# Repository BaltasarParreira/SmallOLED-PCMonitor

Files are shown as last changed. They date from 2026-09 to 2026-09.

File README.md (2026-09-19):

# PC Stats Monitor - ESP32 OLED Display

Youtube Video (https://www.youtube.com/watch?v=D6zZIyOvWjY)

3D Printable case:
0.96": https://makerworld.com/en/models/2051935

1.3": https://makerworld.com/en/models/2185211

2.42" https://makerworld.com/en/models/2341351

Be aware that there are different sizes of the same SSD1306 (0.96") OLED screen on aliexpress.
Im using this one "Original" version (do not purchase dual color, it won't work):
It seems that there is also "New" screen version which comes in another 2 sizes. So be sure to pick correct 3D printable case from link above.
https://aliexpress.com/item/1005006262908701.html

For 1.3" OLED (SH1106) I have used this version:
https://aliexpress.com/item/1005009757205826.html

For 2.42" OLED (SSD1309) I have used this version:
https://aliexpress.com/item/4000002579405.html

For 1.54" OLED (CH1116) I have used this version:
https://aliexpress.com/item/1005006579037427.html

ESP32-C3 SuperMini:
https://aliexpress.com/item/1005008988143743.html

HOW TO Video assembly (you can ignore LED if you are not going to use it):

Version with LED based on 2n2222: https://www.youtube.com/watch?v=umV7xA0mp5I

Version with LED based on LDO6AJSA https://www.youtube.com/watch?v=M2Oa4PDUUgE

I have noticed that some of the cheap ESP32-C3 boards have WiFi related issues on hardware level. After some additional implementations to the code in attempt to fix issues (v1.2.1), some of those issues cannot be fixed as they are on hardware level.
What has helped a bit: Soldering 2 pins to the side of antenna. Check video assembly where I'm sixing that issue.
Some of those faulty boards have antenna too close to other components. Like in this example (left side with 3.5mm gap is better)



> **Note:** Some ESP32-C3 SuperMini boards (especially the external antenna variant) have a very bright built-in RGB LED (WS2812) on GPIO 8. Since GPIO 8 is used for I2C SDA, this LED cannot be turned off via software. If it bothers you, desolder the LED or cut its data trace on the PCB.

A real-time PC monitoring system that displays CPU, RAM, GPU, and disk stats on a small OLED screen using ESP32 and a companion Python script.

## Custom PCB, sponsored by PCBWay

There is now a 27 x 27 mm carrier PCB that holds the ESP32-C3 SuperMini, the OLED header and the optional filament LED driver on one board, instead of wiring it by hand. **[PCBWay](https://www.pcbway.com/) sponsored this project and manufactured the boards**, SMT assembly included, shown below and in the assembly video.

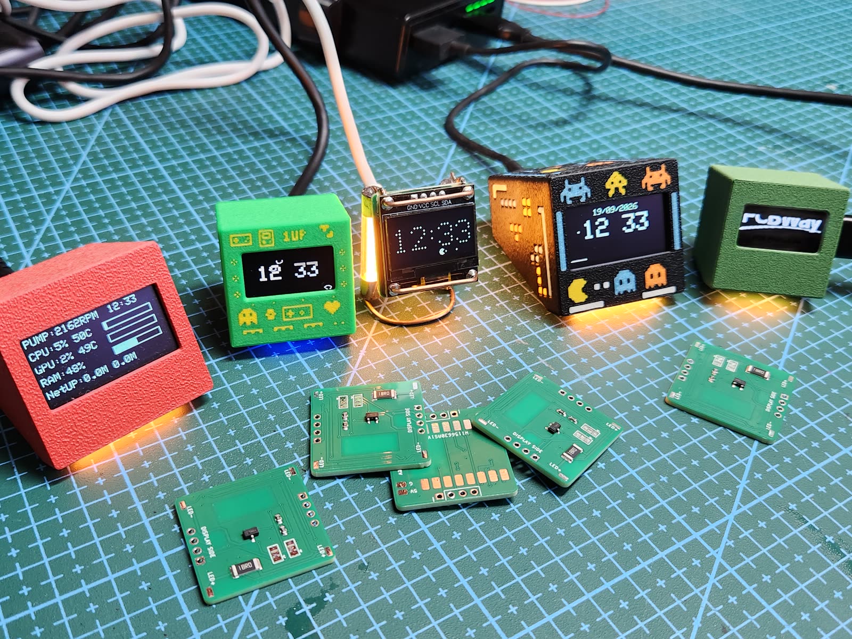
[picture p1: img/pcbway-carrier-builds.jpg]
Finished SmallOLED builds next to unpopulated carrier PCBs


- **[Board details and build notes](CARRIER-PCB.md)**
- **[Order the board from PCBWay](https://www.pcbway.com/project/shareproject/SmallOLED_Carrier_27x27_mm_ESP32_C3_SuperMini_board_for_an_I2C_OLED_PC_stats_m_c42149ed.html)** (gerbers, BOM and pick and place files are attached to the shared project)
- **[Full assembly video](https://youtu.be/5O7uISlaXd4)**: flashing from the browser, soldering, antenna mod and enclosure
- **Cases for this board**: [0.96" (3MF)](case/SmallOLED-Case-0.96-PCB.3mf) and [1.3" retro (3MF)](case/SmallOLED-Case-1.3-Retro-PCB.3mf), two plates each. See [CARRIER-PCB.md](CARRIER-PCB.md#3d-printed-cases) before printing the 1.3" one, it needs a panel-mount USB-C on a lead

## Features

- **Dual Display Modes:**
  - **PC Online**: Real-time stats with customizable metrics and positions
  - **PC Offline**: Animated clock (Mario, Space Invaders, Arkanoid, Pac-Man, Snake, Tetris, Asteroids, Dino Runner, TRON, Standard, or Large styles, plus a Cycle All mode)
- **Audio Visualizer**: Live spectrum bars or an oscilloscope driven by whatever your PC is playing, streamed by the companion app
- **PC Companion App (v4, Windows + Linux)**:
  - Web-style config window that mirrors the device portal 1:1
  - Live 1:1 OLED preview with drag-and-drop layout
  - Sensor picker with live values, up to 20 metrics
  - Custom labels (max 10 characters), number formats, quick templates
  - Optional audio visualizer stream, with auto-switch when music starts
  - Runs in a native window + system tray; **Start with Windows** autostart
  - Windows prebuilt exe (no Python) or Linux from source
- **Web Configuration Portal**: Customize all settings via browser
  - 5-row (spacious) or 6-row (compact) display modes
  - Large 2-row and 3-row modes for readability at a distance
  - Progress bars for visual representation
  - Clock styles and animation settings
  - Automatic timezone with DST support (56 regions)
  - Display brightness control and scheduled night dimming
  - Export/Import configuration
  - OTA firmware updates
- **Browser Web Flasher (Preferred)**: Install firmware and push WiFi credentials entirely from the browser over USB - no tools to install
- **WiFi Portal**: Easy first-time setup without code changes (fallback / build-from-source path)
- **mDNS Discovery**: Access your device via `http://smalloled.local` (configurable name)
- **Optimized Performance**: Minimal CPU usage on PC (<1%)
- **Persistent Settings**: All preferences saved to ESP32 flash memory

## Quick Start for Beginners

**Never done this before? Here's the simple version:**

1. **Flash ESP32** - Open the [SmallOLED Web Flasher](https://smalloled.stolaris.dev/) in desktop Chrome or Edge, pick your OLED, and click Install (no installation needed!)
2. **Connect ESP32 to WiFi** - Right after flashing, use the flasher's **Configure WiFi** step to send your network to the device over USB. (No web flasher? Join the "PCMonitor-Setup" network and open 192.168.4.1.)
3. **Install LibreHardwareMonitor** (Windows only) - Download from [GitHub](https://github.com/LibreHardwareMonitor/LibreHardwareMonitor/releases), run as Admin (needed for temps/fans/GPU/power)
4. **Get the companion app (v4 - recommended on both Windows and Linux):**
   - **Windows (easiest):** download `pc_stats_monitor_v4.exe` from the [latest release](https://github.com/Keralots/SmallOLED-PCMonitor/releases/latest) and double-click it - no Python needed. v4 gives a polished **web-style config window** (1:1 device preview, drag-and-drop layout, sensor picker, number formats, quick templates) that lives in the system tray. On the first run Windows SmartScreen may say *"Windows protected your PC"* - the exe is unsigned, so click **More info -> Run anyway**. This is normal for small unsigned tools.
   - **Linux:** `cd PC-Companion-App-v4/linux-companion`, then `python3 -m pip install -r requirements.txt` and `python3 pc_stats_monitor_v4_linux.py` (no build step). Same UI; opens a native window or your browser.
5. **Configure in GUI** - Enter ESP32 IP address, select the sensors you want, click "Save & Start"
6. **Position metrics** - use the app's **Layout & preview** page, or open the ESP32 IP in a browser and drag metrics on the device's own preview

Done! Your PC stats will now appear on the OLED display.

For detailed instructions, keep reading below.

## Hardware Requirements

### ESP32 Setup
- **ESP32-C3 Super Mini** (or compatible ESP32 board)
- **OLED Display** (128x64, I2C):
  - SSD1306 0.96" (most common)
  - SH1106 1.3" (larger, recommended)
  - CH1116 1.54" (SH1106-compatible, own firmware)
  - SSD1309 2.42" (largest, uses same firmware as 0.96")
- **TTP223 Touch Sensor** (optional - for physical button control)
- **Wiring (I2C):**
  - SDA → GPIO 8
  - SCL → GPIO 9
  - VCC → 3.3V
  - GND → GND
  - TTP223 Signal → GPIO 7 (optional)
  - LED Transistor Base or LDO6AJSA PWM → GPIO 1 (optional)

Wiring



### Touch Button (Optional)
##### Wiring for optional filament led and TTP223 sensor

This wiring is for 2.42" OLED. Use the same firmware as for 0.96" OLED for flashing.
No need to change firmware, TTP223 and LED will work.

If you are using 2N2222 and resistors for led here is the wiring:


If you are using LDO6AJSA here is the wiring:


The firmware supports an optional **TTP223 capacitive touch sensor** for physical control of the display and LED night light:

**Button Gestures:**

| Gesture | Duration | Action |
|---|---|---|
| Quick tap | < 500ms | **PC online:** Toggle metrics/clock. **PC offline:** Cycle clock styles |
| Medium press | 500ms-1s, release | Toggle LED night light on/off |
| Long hold | > 1s, keep holding | Ramp LED brightness up (if off) or down (if on). Release to keep. |

**Hardware Setup:**
- Connect TTP223 signal pin to GPIO 7
- Power the TTP223 with 3.3V and GND

**Configuration** (in `src/config/user_config.h`):
```cpp
#define TOUCH_BUTTON_ENABLED 1      // 1 = enabled, 0 = disabled
#define TOUCH_BUTTON_PIN 7          // GPIO pin (default: 7)
#define TOUCH_DEBOUNCE_MS 50       // Debounce delay (default: 100ms)
#define TOUCH_ACTIVE_LEVEL HIGH     // HIGH for TTP223 (active HIGH)
```

## Software Setup

### 1. ESP32 Firmware

#### Option A: SmallOLED Web Flasher (Preferred - No Installation Needed)

A dedicated browser flasher that picks the right firmware for your OLED, installs it over USB, and then hands your WiFi to the device in the same tab. No separate flashing tool and no captive portal needed.

1. Open the **[SmallOLED Web Flasher](https://smalloled.stolaris.dev/)** in desktop **Chrome or Edge** (Web Serial is required, so Firefox, Safari and mobile won't work).
2. Connect your ESP32-C3 via USB. If it constantly connects/disconnects, hold the **BOOT** button, connect to USB while still holding it, then release after connecting. Alternatively, hold **BOOT**, press **RESET** while holding **BOOT**, then release both buttons.
3. Pick your OLED (0.96" SSD1306, 1.3" SH1106, 1.54" CH1116, or 2.42" SSD1309) and click **Install**. It erases and writes the full image at `0x0` in ~30 seconds.
4. When the install finishes, use the **Configure WiFi** step to send your home network to the device over USB. If you miss it, join the **PCMonitor-Setup** hotspot and open `192.168.4.1` instead.
5. The device reboots, joins your WiFi, and shows its IP address on the OLED.

> The same page has a built-in serial monitor (section 04) for grabbing boot logs if you ever need them for a bug report.

#### Option B: Manual Pre-built Binary (Optional)

Prefer to flash the raw binary with your own tool? Download it from the latest release and flash the full image at `0x0`.

**Download the latest release**: grab the full image for your OLED size from the [Releases tab](https://github.com/Keralots/SmallOLED-PCMonitor/releases/latest).

**Generic web flasher (esptool-js):**
1. Visit [ESP Web Flasher](https://espressif.github.io/esptool-js/)
2. Connect your ESP32-C3 via USB (use the BOOT/RESET trick above if it won't stay connected).
3. Click **"Connect"** and select your port
4. Click **"Choose File"** and select the full image for your display, e.g. `firmware-<version>-OLED_0.96inch.bin`
5. Make sure you pick firmware for correct OLED size version! It may initially work but you will get black screen after you reconnect device.
6. Set **Flash Address** to `0x0`
7. Click **"Program"** and wait ~30 seconds
8. Done! Then set up WiFi via the **PCMonitor-Setup** hotspot (see below).

**Other methods:**
- **Windows**: Run `flash.bat` and follow prompts
- **Linux/Mac**: Run `./flash.sh` and follow prompts
- **Manual**: `esptool.py --chip esp32c3 --port COM3 --baud 460800 write_flash 0x0 firmware-<version>-OLED_0.96inch.bin`

#### Option C: Build from Source

**Prerequisites:**
- [PlatformIO](https://platformio.org/) (or Arduino IDE)

**Installation:**
1. Clone this repository
2. Open the project in PlatformIO
3. Connect your ESP32 via USB
4. Build and upload:
   ```bash
   pio run --target upload
   ```

#### First-Time WiFi Setup

> Flashed with the SmallOLED Web Flasher (Option A)? You can skip this - set WiFi from the browser's **Configure WiFi** step right after flashing. The access-point method below is the fallback, and the path when you build from source.

1. After uploading, the ESP32 will create a WiFi access point
2. Connect to the network: **PCMonitor-Setup**
3. Open your browser to `192.168.4.1`
4. Configure your WiFi credentials
5. The ESP32 will connect and display its IP address on the OLED

#### Web Configuration Portal
Once connected to WiFi, access the full configuration page:
1. Open a browser and navigate to the ESP32's IP address (shown on OLED) or `http://smalloled.local`

ESP32 Web Portal - Clock Settings

2. **Clock Settings:**
   - Idle clock style (Mario, Space Invaders, Arkanoid, Pac-Man, Snake, Tetris, Asteroids, Dino Runner, TRON, Standard, or Large, plus a Cycle All mode)
   - Time format (12/24 hour)
   - Date format (DD/MM/YYYY, MM/DD/YYYY, or YYYY-MM-DD)

3. **Display Layout:**
   - Choose between 5-row (spacious, 13px) or 6-row (compact, 10px) modes
   - Large 2-row and 3-row modes for double-size text
   - Enable progress bars for visual representation
   - Row 6 positions automatically hidden in 5-row mode
4. **Timezone:**
   - Select your region from 56 timezone presets
   - Automatic DST transitions (no manual toggle needed)
5. **Visible metrics (custom labels & placement):**
   - Give each metric a custom label (max 10 chars) shown on the OLED - e.g. relabel a pump RPM sensor as "PUMP", "FAN" or "COOLER"
   - Drag a metric chip onto the live OLED preview (or tap a chip then a slot) to place it
   - Pair two metrics on one row and add progress bars
   - Labels can also be set from the companion app
6. **Configuration:**
   - Export configuration to JSON file (backup)
   - Import configuration from JSON file (restore)
   - Reset to factory defaults

### 2. PC Stats Sender

> **Recommended (v4, Windows + Linux):** the v4 companion gives a web-style
> config window that mirrors the device portal 1:1 - live OLED preview, drag-and-drop
> layout, sensor picker, number formats, quick templates, pull/push and backup -
> all from the desktop, hosted in a native window + system tray.
> - **Windows:** prebuilt **`pc_stats_monitor_v4.exe`** on the [latest release page](https://github.com/Keralots/SmallOLED-PCMonitor/releases/latest) - no Python needed. First run may trip Windows SmartScreen (unsigned exe): **More info -> Run anyway**. Source and the full guide live in [`PC-Companion-App-v4/win-companion/`](PC-Companion-App-v4/win-companion/).
> - **Linux:** run from source in [`PC-Companion-App-v4/linux-companion/`](PC-Companion-App-v4/linux-companion/) (`pip install -r requirements.txt` then `python3 pc_stats_monitor_v4_linux.py`).

#### Installing Python (only if you run from source)

The Windows exe bundles its own Python, so skip this unless you run the app from source (always the case on Linux).
For Windows download [e.g. this version](https://www.python.org/ftp/python/3.14.2/python-3.14.2-amd64.exe)
Check both checkboxes on installation screen (to use admin rights and add python.exe to PATH)



At the end of installation, if asked to remove characters limit for path, agree on it.

#### Installing LibreHardwareMonitor
1. Download from [LibreHardwareMonitor](https://github.com/LibreHardwareMonitor/LibreHardwareMonitor/releases)
2. Extract and run `LibreHardwareMonitor.exe` as Administrator
3. Windows defender may block it from running. This is false/positive, just add it to exception.
4. Check following options. First 4 from the top:


For version 0.9.5 and above check Web server option:
lhw-webserver

LibreHardwareMonitor 0.9.5+ broke its WMI backend. The companion app detects that and falls back to the REST API, which is what the Web server option above serves - so on 0.9.5+ that option is not optional.

#### Set up the companion app

The recommended **v4 companion** (Windows exe or Linux from source, see above) opens its config window automatically and also lives in the system tray - right-click the tray icon to reopen it or quit.

System tray icon

##### Step 1: Launch the app

**Windows:** double-click `pc_stats_monitor_v4.exe`. First run may trip Windows SmartScreen (unsigned exe): **More info -> Run anyway**.

**Linux:**
```bash
cd PC-Companion-App-v4/linux-companion
python3 -m pip install -r requirements.txt
python3 pc_stats_monitor_v4_linux.py
```

##### Step 2: Connect to your ESP32

Companion app - connection

On the **Connection** page:

1. **Enter the ESP32 IP Address** - shown on the OLED at boot.
2. **UDP Port** (default 4210) and **Update Interval** (default 3s) - leave unless you changed them.
3. **Sensor source** - leave on **Auto** (prefers the REST API, falls back to WMI). Only force a mode if you have a reason to.
4. Click **Test connection** to confirm the device answers, then **Save connection**.
5. **Autostart (optional).** On Windows, tick **Start with Windows** - saved instantly, launches minimized to the tray at login (per-user, no admin) and waits 10s for LibreHardwareMonitor to come up first. On Linux, `python3 pc_stats_monitor_v4_linux.py --autostart enable` installs a `smalloled-companion.service` systemd user unit (`--autostart disable` removes it).

##### Step 3: Pick the sensors to display

Companion app - sensor picker

On the **Sensors** page:

1. Make sure **LibreHardwareMonitor is running** (Windows) for temps, fans, GPU and power - CPU / RAM / Disk work out of the box. In **Auto** source mode the app reads LibreHardwareMonitor over its REST API and falls back to WMI, so 0.9.5+ (with broken WMI) works fine.
2. Browse the categories: System, Temperatures, Fans, Loads, Clocks, Power, Network Data, Network Throughput. Hit **Rescan sensors** if something is missing.
3. **Live current values** are shown next to each sensor so you can identify them.
4. Tick the sensors you want - up to **20 metrics**.
5. Give any sensor a **Custom label** (max 10 chars) to show on the OLED - e.g. relabel a pump RPM sensor "PUMP". Leave empty for the auto name.
6. Click **Save & push to device**. The **Layout & preview** page then lets you drag each metric onto a 1:1 OLED preview.

##### Step 4: Position Metrics on ESP32 Display

Companion app - layout and preview

After the companion app starts sending data (arrange metrics in its **Layout & preview** page, or in the device's own web portal as below):

1. Open your ESP32's IP address in a web browser
2. Open the **Visible metrics** page
3. You'll see all metrics received from your PC as draggable chips under a live OLED preview
4. Drag a chip onto a slot (or tap a chip then a slot) to place it; optionally pair it with a companion metric. E.g. **"CPU: 10% 40C"** > shows usage and temperature of CPU.
5. Use **progress bars** for visual representation (optional)
6. Choose between **5-row** (more spacing), **6-row** (compact) or the **large 2/3-row** display modes on the Display layout page

**TIP:** Start with 1-2 metrics initially and slowly build entire layout.

ESP32 Web Portal - Visible metrics

The display will update in real-time as you arrange metrics!

## Usage

### Normal Operation
1. **ESP32** should be powered and connected to WiFi
2. **LibreHardwareMonitor** must be running on your PC
3. **Companion app** should be running

The OLED will display:
- **PC Online**: Real-time stats (CPU, RAM, GPU temp, disk, fan speed)
- **PC Offline**: Animated clock (choose from 11 styles in the web portal, or a Cycle All mode that rotates through them)

### Display Modes

**When PC is Online (receiving stats):**

There are four stats layouts, switchable in the web portal under **Display layout**. All of them take custom labels, paired companion metrics and progress bars. Each clip below runs the same workload cycle - idle, load, cool down - so you can compare them.

| | |
|:---:|:---:|
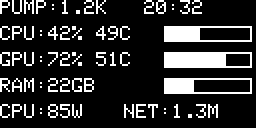
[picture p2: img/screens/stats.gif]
5-row stats layout
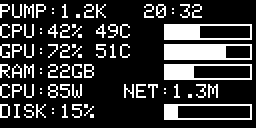
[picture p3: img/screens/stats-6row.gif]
6-row stats layout
| <br>**5 rows** - 13px spacing, positions 0-9. The default, and the easiest to read. | <br>**6 rows** - 10px spacing, positions 0-11. One more row of metrics. |
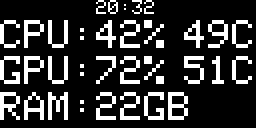
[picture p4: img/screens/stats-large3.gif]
Large 3-row stats layout
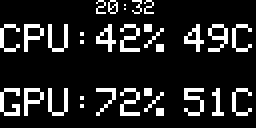
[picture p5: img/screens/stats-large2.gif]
Large 2-row stats layout
| <br>**Large 3 rows** - double-size text, single column, 3 metrics. | <br>**Large 2 rows** - double-size text, 2 metrics, readable across a room. |

- Real-time monitoring display with customizable labels
- Shows CPU usage/temp, RAM usage, GPU temp, Disk usage, Fan/Pump speed
- Progress bars for visual representation
- The 5-row mode drops to 11px spacing when the clock is centered, to keep all five rows on screen
- Automatically switches when PC sends data

**When PC is Offline (idle mode):**

Every clock below is captured at the 09:59 -> 10:00 rollover, the busiest case, since all four digits change at once.

| | | |
|:---:|:---:|:---:|
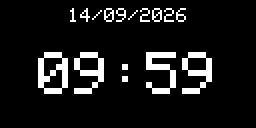
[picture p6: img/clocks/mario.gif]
Mario Clock
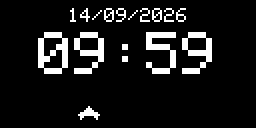
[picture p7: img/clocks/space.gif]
Space Invaders Clock
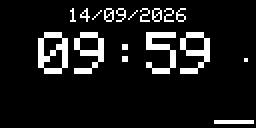
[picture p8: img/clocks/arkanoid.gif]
Arkanoid Clock
| <br>**Mario** | <br>**Space Invaders** | <br>**Arkanoid** |
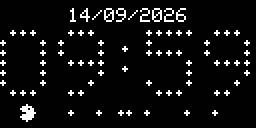
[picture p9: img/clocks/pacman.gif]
Pac-Man Clock
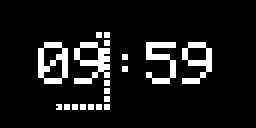
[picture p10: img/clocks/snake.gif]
Snake Clock
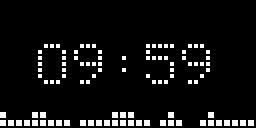
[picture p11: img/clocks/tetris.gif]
Tetris Clock
| <br>**Pac-Man** | <br>**Snake** | <br>**Tetris** |
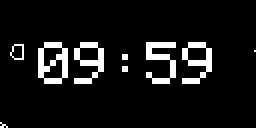
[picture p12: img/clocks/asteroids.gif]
Asteroids Clock
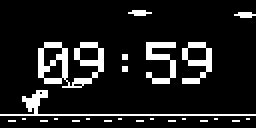
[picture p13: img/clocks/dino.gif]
Dino Runner Clock
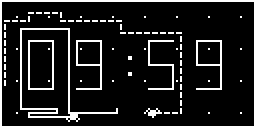
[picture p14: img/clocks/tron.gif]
TRON Clock
| <br>**Asteroids** | <br>**Dino Runner** | <br>**TRON** |
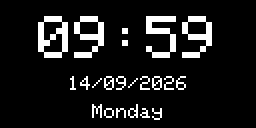
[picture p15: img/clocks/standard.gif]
Standard Clock
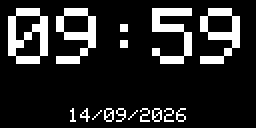
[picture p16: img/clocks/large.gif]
Large Clock
| <br>**Standard** | <br>**Large** | |

- **Mario Clock**: Animated pixel Mario that jumps to "hit" digits when time changes
- **Space Invaders Clock**: Invader/ship shoots lasers to change digits
- **Arkanoid Clock**: Breakout-style ball physics destroy and rebuild digits
- **Pac-Man Clock**: Pac-Man eats pellet-based digits
- **Snake Clock**: A Nokia-style snake roams the screen chasing food and steering around the digits and its own body. On each minute change the changed digits crumble into pellets that the snake hunts down one by one before the new digit drops in. Optional arena border and date row.
- **Tetris Clock**: Block-grid digits sit low on the screen with the occasional tumbling tetromino. On each minute change the changed digits are rebuilt one at a time, either as drop-in slabs or as falling dots. Optional date row at the top or bottom.
- **Asteroids Clock**: A wireframe vector clock - the ship drifts with inertia and splits tumbling rocks while idle, then aims at and shoots each changed digit into spinning line shards at the minute change. Optional date row.
- **Dino Runner Clock**: A Chrome T-Rex homage - the dino runs and auto-jumps cacti over a scrolling ground with parallax clouds; at the minute change a pterodactyl swoops in, carries off the old digit, and the new one drops in from above. Optional clouds and date row.
- **TRON Clock**: Two light cycles duel around the digits, leaving trails behind them (one solid, one dotted, so you can tell them apart). At the minute change one cycle is dispatched to retrace the changed digit stroke by stroke. Optional arena grid and border, and a choice of side-profile or overhead bike sprite.
- **Standard Clock**: Simple centered clock with date and day of week
- **Large Clock**: Extra-large time display with date
- **Cycle All Styles**: Rotates through every clock style automatically, switching every 5 minutes.

Change clock style anytime via the web portal or touch button!

### Customizing Display Labels

**Via Web Portal (Recommended):**
1. Open ESP32's IP address in browser
2. Go to the **Visible metrics** page
3. Expand a metric and set its **Custom label** to match your setup:
   - relabel a pump RPM sensor "PUMP", "FAN" or "COOLER"
   - give CPU, RAM, GPU, Disk metrics your own labels too
4. Changes apply live in the preview; click **Save & apply** to keep them

### Customizing Monitored Sensors

The companion app lets you select any sensor available on your system:

**Available Sensor Categories:**
- **System Metrics**: CPU%, RAM%, Disk usage (using psutil)
- **Temperatures**: CPU cores, GPU, motherboard, drives
- **Fans & Cooling**: All detected fan speeds
- **Loads**: CPU/GPU load percentages
- **Clocks**: CPU/GPU clock speeds
- **Power**: Power consumption sensors
- **Network Data**: Total uploaded/downloaded (in GB)
- **Network Throughput**: Current upload/download speeds (in KB/s or MB/s)

**How to Select Sensors:**
1. Make sure **LibreHardwareMonitor is running** (Windows) for temps/fans/GPU/power. The app falls back to its REST API on 0.9.5+.
2. Open the companion app - double-click `pc_stats_monitor_v4.exe`, or right-click the tray icon and choose open
3. Go to the **Sensors** page and browse the categories
4. **Live current values** are shown next to each sensor to help you identify them
5. Tick the sensors you want to monitor (up to 20)
6. Set custom labels if desired (max 10 characters)
7. Click **Save & push to device** - the OLED updates live

ESP32 Web Portal Example

**Tips:**
- The GUI shows live sensor values when you open it
- Use the search box to quickly find specific sensors
- Network metrics automatically distinguish between upload and download
- You can select up to 20 different metrics
- Labels set in the companion app override the default names on the ESP32

## Audio Visualizer

The display can show what your PC is playing: 32 spectrum bars or an
oscilloscope trace, updated about 25 times a second.

| | | |
|:---:|:---:|:---:|
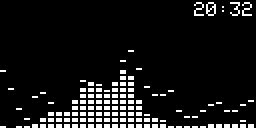
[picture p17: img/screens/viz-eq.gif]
Classic EQ
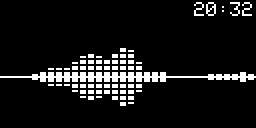
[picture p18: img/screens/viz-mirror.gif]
Mirror EQ
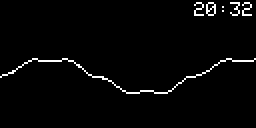
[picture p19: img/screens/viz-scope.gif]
Oscilloscope
| <br>**Classic EQ** | <br>**Mirror EQ** | <br>**Oscilloscope** |

This is a **forced mode**, not a clock style. It needs a live audio stream, so
it is switched on deliberately rather than sitting in the clock rotation, and it
drops back to your normal screen about 10 seconds after the audio stops.

### Turning it on

1. **In the companion app** (Connection page), tick **Audio visualizer stream**.
   The companion captures whatever your PC is playing (WASAPI loopback on
   Windows, PulseAudio monitor on Linux) and sends it to the same UDP port the
   stats already use.
   - Windows: no extra setup.
   - Linux / running from source: needs `soundcard` and `numpy`
     (`pip install soundcard numpy`). The app tells you if they are missing.
2. **Show it on the device**, in any of three ways:
   - Tick **Start the visualizer when music plays** in the companion, and it
     switches the display for you once sound has been playing for the start
     delay, then hands the display back after the quiet period.
   - Press **Show visualizer** on the device's *Audio visualizer* page.
   - Tap the touch button while audio is playing. Tap again to leave.

If the panel says *"No audio data..."*, the device is in visualizer mode but no
stream is arriving - check the companion is running with the stream enabled.

### Settings (device web portal, *Audio visualizer* page)

| Setting | What it does |
|---|---|
| **Visualizer** | Classic EQ (bars from the bottom), Oscilloscope, or Mirror EQ (bars split around a centre line) |
| **Bar texture** | Solid, Segmented (a dark row every third row - reads as an LED ladder), or Outline |
| **Frame rate** | 15-60. See the note below |
| **Peak hold** | A marker that hangs at each band's last peak and falls back under gravity |
| **Corner clock** | Small HH:MM in the top right; costs the top 12 rows |
| **Vertical gain** | Oscilloscope trace height, 50-200% |
| **Ghost trace** | Dotted echo of the previous waveform |
| **Graticule** | Oscilloscope grid. Off by default - it is the same white as the trace, so it competes with it |
| **Fill to centre** | Fills between trace and centre line; goes solid when loud |

**About the frame rate.** These OLED controllers have no double buffering: the
firmware writes straight into the panel's memory while the panel is scanning it
out. Drawing faster than the panel can show it does not look smoother, it looks
torn. The whole 1024-byte framebuffer also has to cross the I2C bus every frame,
which on the stock 400 kHz bus measures **37 fps on a 0.96" SSD1306** and
**33 fps on a 1.3" SH1106** - so those are the real ceilings, whatever the
setting says. The 30 fps default sits comfortably below both. Raise it if you
want; if the picture tears, come back down.

Advanced users can raise the bus itself with `DISPLAY_I2C_CLOCK` in
`src/config/user_config.h` (default `400000`). 800 kHz roughly halves the
transfer time, but it is above what these controllers are specified for and
some panels or longer wiring will corrupt the image rather than fail cleanly.
Change it only if you can watch the panel while you test.

### Oscilloscope needs a recent companion

The waveform is an extra 128 bytes appended to each packet. An older companion
sends only the spectrum, and the oscilloscope will say *"Update PC companion
for the waveform"*. The bar styles work with either.

## HTTP Control API

The firmware exposes a small set of HTTP endpoints for remote control and home automation (e.g. Home Assistant, Node-RED, or a simple `curl` from a script). This is handy for **turning the display off while you're away to extend OLED lifetime**, forcing the clock display, dimming on your own schedule, or rebooting the device remotely.

All endpoints are plain **HTTP GET** (easy to call from any tool), return JSON, and have **no authentication** - anyone on your local network can call them, so keep the device on a trusted LAN.

> **Note:** These controls are **runtime-only** - they are *not* saved to flash and reset to your normal configured behavior after a reboot or power cycle. This is intentional: it avoids flash wear from automations toggling frequently, and lets an external scheduler own the state. To change defaults permanently, use the web configuration portal.

Replace `smalloled.local` in the examples with your device's mDNS name (configurable) or its IP address.

### Endpoints

| Method | Endpoint | Description |
|---|---|---|
| GET | `/api/status` | Return current display/mode state as JSON |
| GET | `/api/display/off` | Turn the display off (panel powered down) |
| GET | `/api/display/on` | Turn the display back on |
| GET | `/api/display/brightness?value=0-100` | Set display brightness (percent) |
| GET | `/api/mode/clock` | Force the animated clock, even when the PC is online |
| GET | `/api/mode/auto` | Resume automatic mode (PC stats when online, clock when offline) |
| GET | `/api/clock/style?id=<id>` | Switch the clock animation |
| GET | `/api/mode/viz` | Show the audio visualizer (needs the companion's audio stream) |
| GET | `/api/viz/style?id=0-2` | Switch the visualizer style |
| GET | `/api/reboot` | Soft-restart the device (does **not** erase settings) |

**Clock style IDs:** `0` = Mario, `1` = Standard, `2` = Large, `3` = Space Invaders, `5` = Arkanoid/Pong, `6` = Pac-Man, `7` = Snake, `8` = Tetris, `9` = Cycle All Styles, `10` = Asteroids, `11` = Dino Runner, `16` = TRON. (The ids are a fixed set, not a range - the gaps are reserved so style numbers stay aligned with the sister project.)

**Visualizer style IDs:** `0` = Classic EQ, `1` = Oscilloscope, `2` = Mirror EQ.

### Examples

```bash
# Turn the display off (e.g. when leaving home) and back on
curl http://smalloled.local/api/display/off
curl http://smalloled.local/api/display/on

# Dim the display to 30%
curl "http://smalloled.local/api/display/brightness?value=30"

# Always show the clock, then go back to automatic
curl http://smalloled.local/api/mode/clock
curl http://smalloled.local/api/mode/auto

# Switch to the Pac-Man clock
curl "http://smalloled.local/api/clock/style?id=6"

# Show the audio visualizer, then pick the oscilloscope
curl http://smalloled.local/api/mode/viz
curl "http://smalloled.local/api/viz/style?id=1"

# Check current state
curl http://smalloled.local/api/status
```

A `/api/status` response looks like:

```json
{
  "displayOn": true,
  "forcedOff": false,
  "mode": "clock",
  "forcedClock": true,
  "brightness": 100,
  "clockStyle": 0,
  "pcOnline": false
}
```

| Field | Meaning |
|---|---|
| `displayOn` | `false` when the panel is off (forced off, or brightness 0) |
| `forcedOff` | `true` if the display was turned off via `/api/display/off` |
| `mode` | `"metrics"` or `"clock"` - what is currently being shown |
| `forcedClock` | `true` if clock mode is being forced via `/api/mode/clock` |
| `brightness` | Current brightness, 0-100% |
| `clockStyle` | Active clock style ID (see list above) |
| `pcOnline` | `true` if the PC sender is currently sending stats |

### Home Assistant example

Add this to your `configuration.yaml` to expose the display on/off controls as commands:

```yaml
rest_command:
  oled_display_off:
    url: "http://smalloled.local/api/display/off"
  oled_display_on:
    url: "http://smalloled.local/api/display/on"
```

You can then call `rest_command.oled_display_off` / `oled_display_on` from an automation - for example, turn the display off when everyone leaves home and back on when someone arrives.

## Troubleshooting

### ESP32 Issues

**Display not working**
- Check I2C wiring (SDA=GPIO8, SCL=GPIO9)
- Verify I2C address is 0x3C (common for SSD1306)
- For SH1106 (1.3"): change `DEFAULT_DISPLAY_TYPE` to `1` in `user_config.h`
- For CH1116 (1.54"): change `DEFAULT_DISPLAY_TYPE` to `2` in `user_config.h`
- For SSD1309 (2.42"): use `DEFAULT_DISPLAY_TYPE` `0` (same as 0.96", no change needed)

**Can't connect to WiFi portal**
- Make sure you're connected to "PCMonitor-Setup" network
- Try accessing `192.168.4.1` in your browser
- Reset WiFi settings via web interface

**ESP32 keeps restarting**
- Check power supply (use quality USB cable)
- Monitor serial output at 115200 baud for error messages

### Companion App Issues

**The config window doesn't open**
- Windows: the exe is unsigned, so SmartScreen may hold it on the first run - **More info → Run anyway**. Once it is running, right-click the tray icon to reopen the window.
- Linux: a native window needs the system GTK/WebKit libraries (`sudo apt install gir1.2-webkit2-4.1 python3-gi`). Without them the app still runs and serves the same UI in your browser at `http://127.0.0.1:8737`.

**Hardware sensor errors (Windows)**
- Make sure **LibreHardwareMonitor is running as Administrator** - without admin it reports no temps, fans or power
- Check that the WMI service is running: `services.msc` → Windows Management Instrumentation

**No sensors showing (Windows)**
- Start LibreHardwareMonitor **before** the companion app, and give it a few seconds
- On LibreHardwareMonitor 0.9.5+, enable Options → Remote Web Server → Run. Its WMI backend is broken; the app falls back to the REST API, which that option serves
- Leave **Sensor source** on **Auto** unless you have a reason to force a mode, then hit **Rescan sensors**

**No data on ESP32 display**
- Verify the ESP32 IP address on the **Connection** page matches the one shown on the OLED, and use **Test connection**
- Check Windows Firewall isn't blocking UDP port 4210
- Ensure both PC and ESP32 are on the same network
- Open the ESP32 web interface and check the **Visible metrics** page - metrics arrive unplaced until you position them

**Autostart not working (Windows)**
- The **Start with Windows** tick box writes an HKCU Run entry; check Task Manager → Startup
- It launches minimized to the tray, so look for the tray icon rather than a window

**Autostart not working (Linux)**
- Check service status: `systemctl --user status smalloled-companion`
- View logs: `journalctl --user -u smalloled-companion -f`
- Make sure systemd is available on your system
- Enable lingering (optional): `loginctl enable-linger $USER`

**Network metrics not showing (Linux)**
- Network metrics use psutil's `net_io_counters()`
- Upload/download speeds are calculated from byte deltas
- First reading will always be 0, wait for next update cycle

**Audio visualizer says "No audio data..."**
- The device is in visualizer mode but nothing is arriving - tick **Audio visualizer stream** on the companion's Connection page
- Linux / running from source also needs `soundcard` and `numpy`, and a PulseAudio/PipeWire monitor source for the default output

**Custom labels not appearing on ESP32**
- Set them on the companion's **Sensors** page (max 10 characters), then **Save & push to device**
- They can also be set per metric in the device's own **Visible metrics** page

## Technical Details

### Communication
- **Protocol**: UDP
- **Port**: 4210 (configurable)
- **Format**: JSON
- **Update Rate**: 3 seconds (configurable in the app)
- **Max Metrics**: 20
- **Audio stream**: same UDP port, ~25 packets/s, spectrum plus an optional 128-byte waveform

### Companion App Internals
- **JSON configuration** in `%APPDATA%\SmallOLED-Companion\monitor_config.json` (Windows) or `~/.config/smalloled-companion/monitor_config.json` (Linux)
- **Dynamic sensor discovery** - detects every sensor the system exposes
- **REST API fallback** - automatic support for LibreHardwareMonitor 0.9.5+ (broken WMI)
- **Network metrics** calculated in real-time (upload/download speeds)
- **Export/Import** configuration for easy backup and sharing
- **Systemd integration** (Linux) for proper service management

### Libraries Used

**ESP32:**
- WiFiManager (tzapu)
- Adafruit SSD1306 / Adafruit SH110X
- Adafruit GFX
- ArduinoJson

**Companion app (Windows):**
- psutil (system stats & network)
- pywin32/wmi (LibreHardwareMonitor integration)
- pywebview (native window hosting the local web UI)
- pystray/pillow (system tray)

**Companion app (Linux):**
- psutil (system stats, temps, fans, network)
- pywebview (native window, falls back to the browser)
- soundcard/numpy (audio visualizer - optional)

### File Structure
```
PC-Companion-App-v4/
  companion-common/     # shared UI, server and protocol code
  win-companion/        # Windows app, source of pc_stats_monitor_v4.exe
  linux-companion/      # Linux app, run from source
monitor_config.json     # per-user config (auto-generated, see path above)
```

## Advanced / Optional Features

These features are **disabled by default** and require recompilation. They are configured in `src/config/user_config.h` and are intended for advanced users who build from source.

### Display Type Selection

Change `DEFAULT_DISPLAY_TYPE` to match your OLED:

| Value | Display | Size | Notes |
|---|---|---|---|
| `0` | SSD1306 | 0.96" / 2.42" | Default. Works for both 0.96" SSD1306 and 2.42" SSD1309 |
| `1` | SH1106 | 1.3" | 132x64 RAM with 2-column offset |
| `2` | CH1116 | 1.54" | SH1106-compatible, no column offset ([example panel](https://aliexpress.com/item/1005006579037427.html)) |

### SPI Display Interface

By default, displays connect via I2C (2 wires). For faster refresh rates (useful for smooth animations), you can use SPI instead.

```cpp
#define DISPLAY_INTERFACE 1          // 0 = I2C (default), 1 = SPI
```

**SPI pin assignments** (ESP32-C3):
| Signal | GPIO | Notes |
|---|---|---|
| MOSI (SDA) | 6 | Data |
| SCK | 4 | SPI Clock |
| CS | 5 | Chip Select |
| DC | 3 | Data/Command |
| RST | 10 | Reset (-1 if not connected) |

### LED PWM Night Light

Drive a filament LED (or any LED) via a 2N2222 transistor on GPIO 1. Controlled via TTP223 touch gestures (medium press toggles, long hold ramps brightness with gamma correction).

```cpp
#define LED_PWM_ENABLED 1            // 0 = disabled (default), 1 = enabled
#define LED_PWM_PIN 1                // GPIO pin (default: 1)
```

See the [wiring diagram](img/circuit_image.png) for the transistor circuit.

### QR Code WiFi Setup

Show a scannable QR code on the OLED during WiFi AP setup instead of text instructions. Useful for mobile phone setup.

```cpp
#define QR_SETUP_ENABLED 1           // 0 = text instructions (default), 1 = QR code
```

### BLE WiFi Provisioning (Experimental)

Bluetooth Low Energy setup for the **SmallOLED Android app** (currently in development). Instead of the WiFi AP portal, the ESP32 advertises as a BLE device. The Android app discovers it, sends WiFi credentials over BLE, and the device connects automatically.

```cpp
#define BLE_SETUP_ENABLED 1          // 0 = AP mode (default), 1 = BLE provisioning
#define BLE_DEVICE_NAME "SmallOLED"  // BLE advertised name
```

**How it works:**
1. On first boot (no saved WiFi), device starts BLE advertising
2. Android app scans and finds "SmallOLED"
3. App sends your home WiFi SSID + password over BLE
4. Device connects to WiFi and saves credentials
5. Subsequent boots connect silently (no BLE needed)
6. If BLE times out (2 min) or fails, falls back to AP mode automatically

**Requirements:**
- `min_spiffs.csv` partition table (already set in `platformio.ini`)
- NimBLE library (already included in `platformio.ini`)
- Android app (in development, not yet publicly released)

### Scheduled Display Dimming

Automatically dim the display during nighttime hours. Configured via the web interface under Display Settings:
- **Enable/disable** scheduled dimming
- **Start/end hours** (e.g., 10 PM to 7 AM)
- **Dim brightness level** (0-255)

### OTA Firmware Updates

Upload new firmware wirelessly through the web interface at `http://<device-ip>/update`. No need to physically connect USB after the initial flash.

## License

This project is open source. Feel free to modify and share!

## Credits

Created for monitoring PC stats on a small OLED display. Mario animation inspired by classic pixel art.

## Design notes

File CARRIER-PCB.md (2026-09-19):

# SmallOLED Carrier PCB

A purpose-built carrier board for SmallOLED. It replaces the hand-wired build with a single 27 x 27 mm PCB that holds the ESP32-C3 SuperMini, the OLED header and the optional filament LED driver, so the whole device fits cleanly inside the 3D printed enclosure.

**The PCBs for this board were provided by [PCBWay](https://www.pcbway.com/), who sponsored the assembly video below.**

Finished SmallOLED builds next to unpopulated carrier PCBs

## Board at a glance

| | |
|---|---|
| Size | 27 x 27 mm |
| Layers | 2 |
| Thickness | 1.6 mm |
| Controller | ESP32-C3 SuperMini, soldered flat onto 16 elongated SMD lands |
| Display | 4-pin I2C header: GND, VCC, SCL, SDA |
| Displays that fit | 0.96" SSD1306 and 1.3" SH1106 |

The SuperMini has no pin headers on this board. It is soldered straight onto the carrier lands, which is what keeps the stack low enough for the small enclosure.

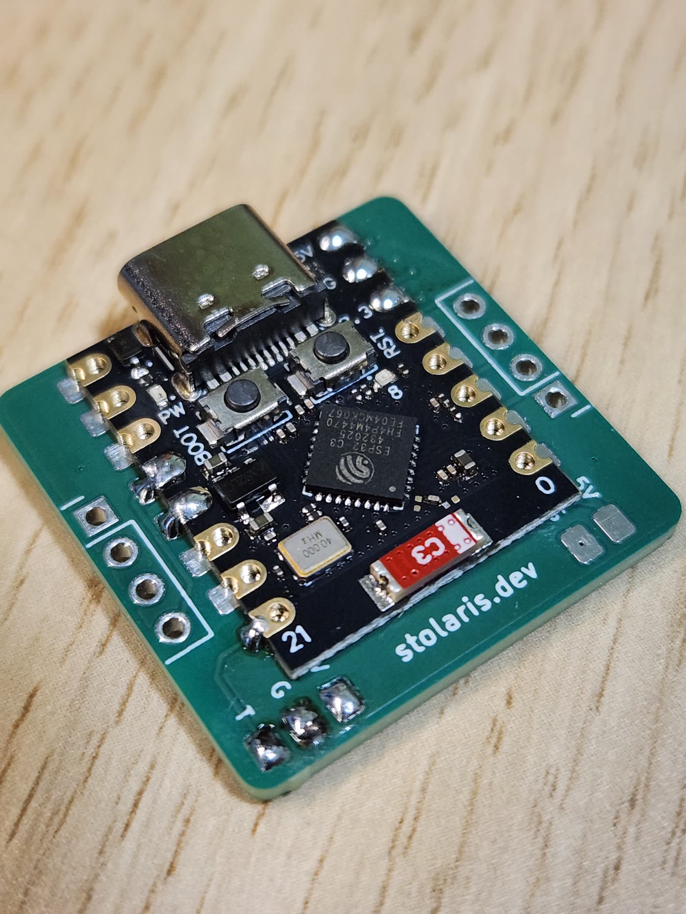
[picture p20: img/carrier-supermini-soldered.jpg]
ESP32-C3 SuperMini soldered flat onto the carrier lands


Four parts are surface mount on the bottom side. PCBWay assembled these at the factory, so the boards arrived ready to build on:

| Ref | Part |
|---|---|
| Q1 | AO3400A |
| R1 | 18R 2010 |
| R2 | 100R 0603 |
| R3 | 10k 0603 |

Everything else is hand soldered. The full build is shown in the video.

## Building a 1.3 inch unit

The same 27 x 27 mm carrier drives the 1.3" SH1106 through the 4-pin I2C header. These shots are from a 1.3" build with the optional TTP223 touch button and a filament LED, going into the dedicated 3D printed case.

<table>
  <tr>
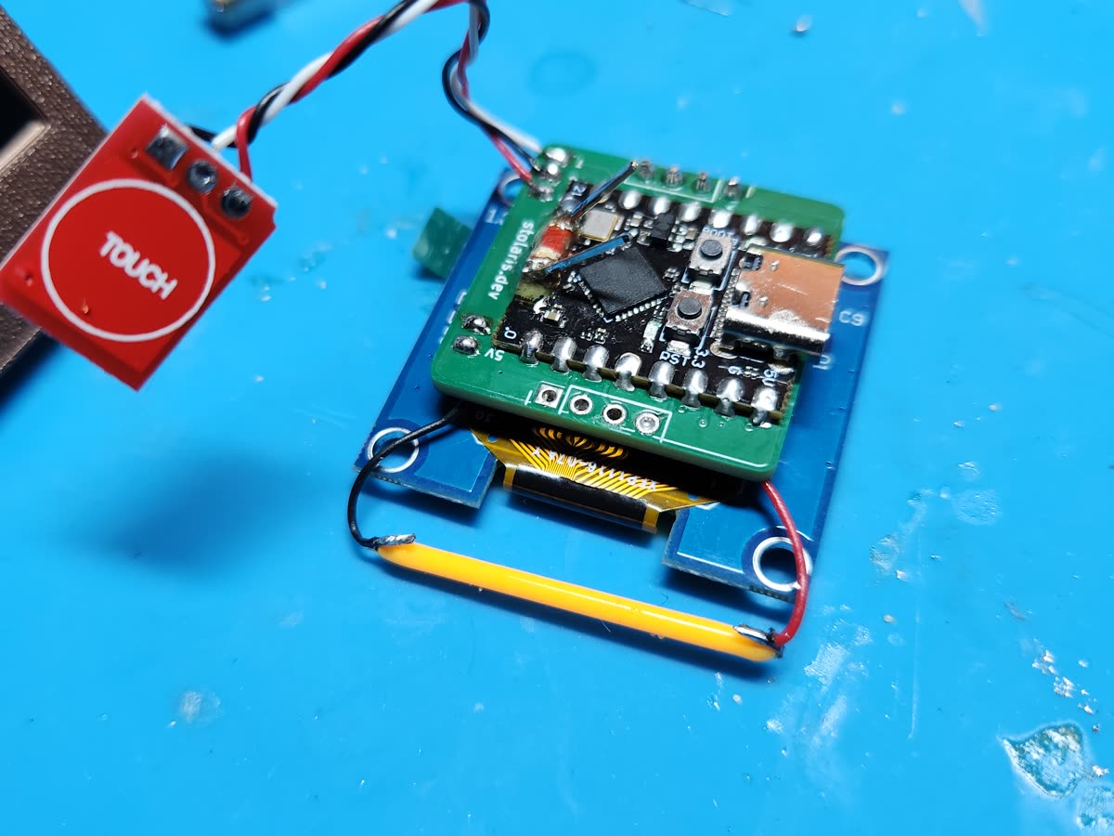
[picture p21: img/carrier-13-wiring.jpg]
Carrier with the 1.3 inch display, touch button and filament LED wired up
    <td width="50%"></td>
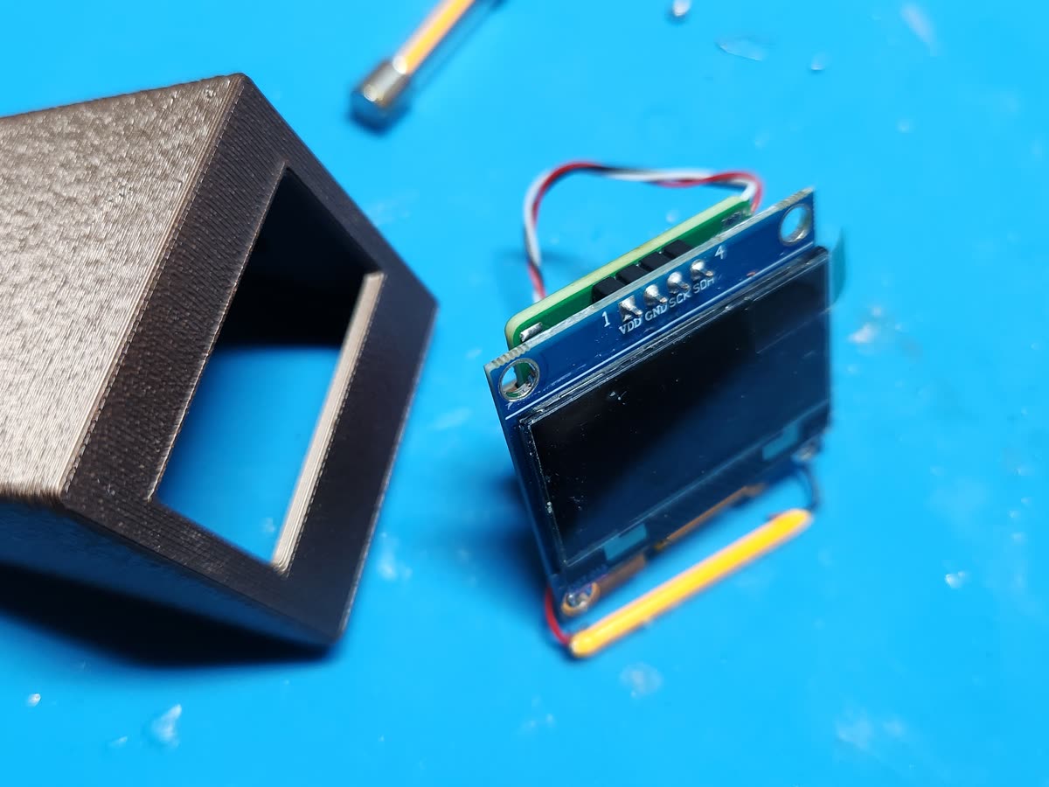
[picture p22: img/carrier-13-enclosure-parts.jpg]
Enclosure frame next to the display and filament LED
    <td width="50%"></td>
  </tr>
  <tr>
    <td><sub>Display, touch button and filament LED soldered to the carrier.</sub></td>
    <td><sub>The printed frame and the display, ready to go together.</sub></td>
  </tr>
  <tr>
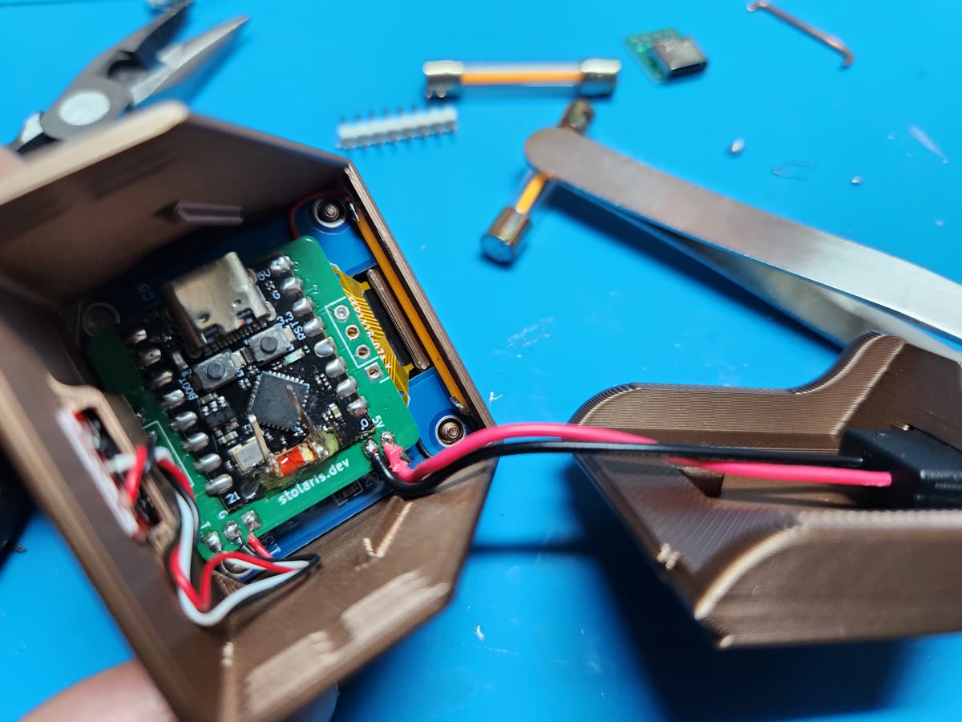
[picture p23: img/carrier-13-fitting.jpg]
Fitting the assembled electronics into the printed case
    <td width="50%"></td>
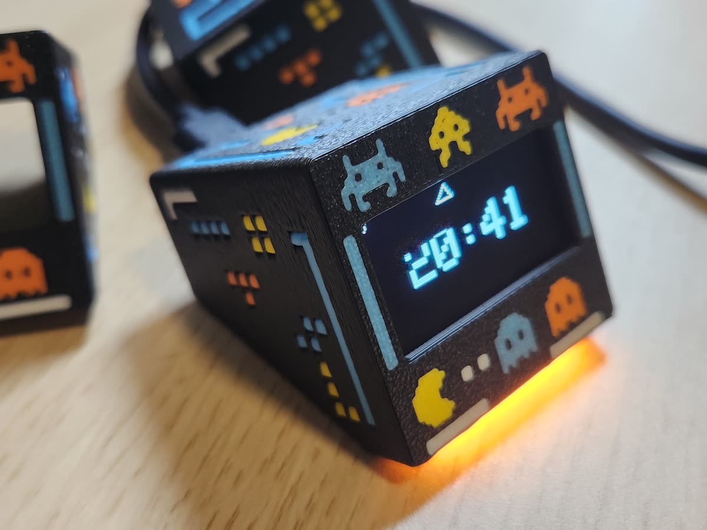
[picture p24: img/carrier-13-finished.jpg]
Finished 1.3 inch SmallOLED showing the clock
    <td width="50%"></td>
  </tr>
  <tr>
    <td><sub>Everything folds into the case.</sub></td>
    <td><sub>Finished unit, filament LED lit.</sub></td>
  </tr>
</table>

## 3D printed cases

These cases live in this repository rather than on MakerWorld, because they only fit the carrier PCB. Both are Bambu Studio projects, and each project has two plates holding everything needed for one device.

| Display | Download | Plate 1 | Plate 2 |
|---|---|---|---|
| 0.96" SSD1306 | [3MF](case/SmallOLED-Case-0.96-PCB.3mf) | `no front graphics`, plain face | `front graphics`, retro motifs on the face |
| 1.3" SH1106 | [3MF](case/SmallOLED-Case-1.3-Retro-PCB.3mf) | `FuzzySkin on black`, textured shell | `No fuzzy skin`, smooth shell |

On the 0.96" case, the front graphics plate is painted across several filaments, so print that one with an AMS or accept a single colour.

**The 1.3" case has no USB-C opening in the side wall.** It is built around a panel-mount USB-C socket on a flying lead, [like this one](https://aliexpress.com/item/1005007148475800.html), soldered to the 5V and GND pads on the carrier instead of using the SuperMini's own connector. Get one before you print this case.

Cases for the 1.54" and 2.42" displays are the standard hand-wired builds and stay on MakerWorld, linked at the top of the [README](README.md).

## Assembly video

[Build a SmallOLED PC Monitor: ESP32-C3, custom PCB and 3D printed case](https://youtu.be/5O7uISlaXd4)

The video covers flashing the firmware from a browser, unboxing the boards, soldering the controller and the OLED, the optional antenna modification, and fitting everything into the enclosure.

## Ordering the board

The board is published as a PCBWay Shared Project, with gerbers, BOM and pick and place files attached:

**[Order the SmallOLED Carrier from PCBWay](https://www.pcbway.com/project/shareproject/SmallOLED_Carrier_27x27_mm_ESP32_C3_SuperMini_board_for_an_I2C_OLED_PC_stats_m_c42149ed.html)**

Ordering through the shared project page also returns 10% to the project.

## Sponsorship

PCBWay manufactured the boards used in the assembly video and in the photos above, including the SMT assembly of the transistor and the three resistors, and supplied them at no cost. The board design, the firmware and everything else in this repository are my own work, and nothing about the project changed in exchange for the boards.

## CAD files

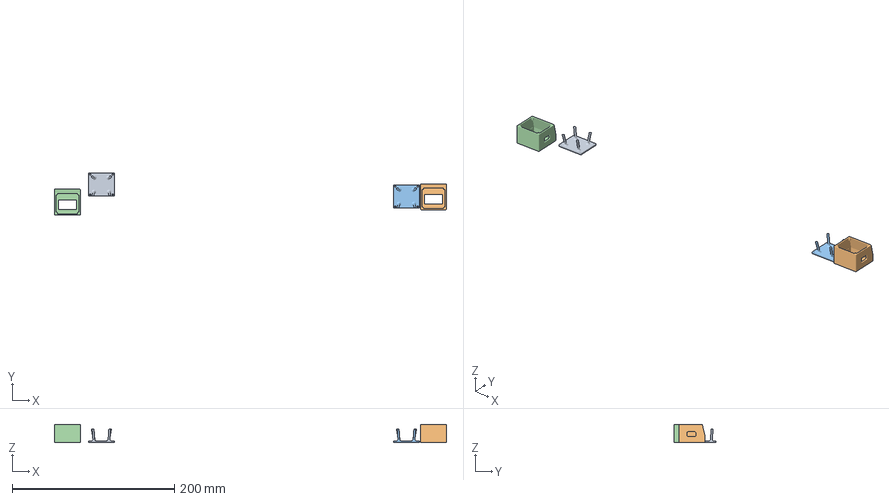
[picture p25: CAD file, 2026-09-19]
case/SmallOLED-Case-0.96-PCB.3mf
483.9 x 51.9 x 22.5 mm
Back x 2
MainBody (1)
MainBody

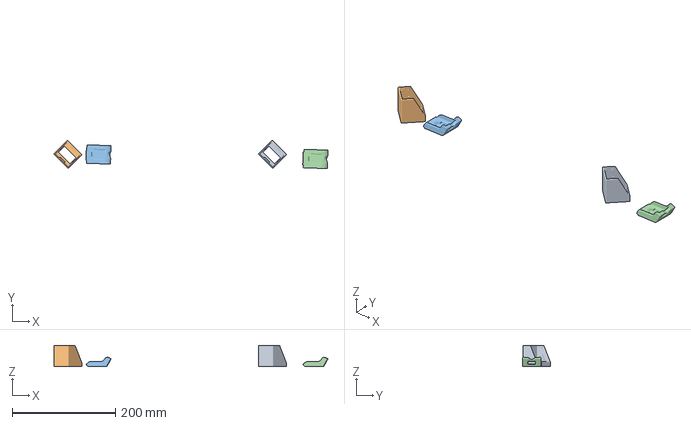
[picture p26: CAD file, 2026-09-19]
case/SmallOLED-Case-1.3-Retro-PCB.3mf
530.5 x 54.6 x 41.4 mm
OLED13 Retro v2 - body, NO rear x 2

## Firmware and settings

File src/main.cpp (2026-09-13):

/*
 * SmallOLED-PCMonitor - Main Entry Point
 *
 * ESP32-C3 with SSD1306/SH1106 OLED display
 * Dual-mode: PC monitoring metrics OR animated clock displays
 */

// ========== User Configuration ==========
// Edit src/config/user_config.h to configure display type, WiFi, and I2C pins
#include "config/user_config.h"

// Use DEFAULT_DISPLAY_TYPE from user_config.h if DISPLAY_TYPE not already
// defined
#ifndef DISPLAY_TYPE
#define DISPLAY_TYPE DEFAULT_DISPLAY_TYPE
#endif

#include <Adafruit_GFX.h>
#include <Preferences.h>
#include <WebServer.h>
#include <WiFi.h>
#include <WiFiManager.h>
#if DISPLAY_INTERFACE == 1
#include <SPI.h>
#else
#include <Wire.h>
#endif

#if DISPLAY_TYPE == 2
#include "display/ch1116.h"  // For 1.54" CH1116 (SH1106-compatible, 1-col offset)
#elif DISPLAY_TYPE == 1
#include <Adafruit_SH110X.h> // For 1.3" SH1106
#else
#include <Adafruit_SSD1306.h> // For 0.96" SSD1306
#endif
#include <ArduinoJson.h>
#include <Update.h>
#include <esp_system.h>
#include <esp_task_wdt.h>
#include <time.h>


#include "config/config.h"
#include "utils/utils.h"
#include "timezones.h"
#include "viz/visualizer.h"

// ========== External Objects ==========
extern WiFiUDP udp;              // Defined in network.cpp
extern WebServer server;         // Defined in web.cpp
extern Preferences preferences;  // Defined in settings.cpp

// ========== Display Object ==========
#if DISPLAY_TYPE == 2
  // CH1116 display (1.54", SH1106-compatible with corrected column offset)
  #if DISPLAY_INTERFACE == 1
    Adafruit_CH1116 display(SCREEN_WIDTH, SCREEN_HEIGHT, &SPI, SPI_DC_PIN, SPI_RST_PIN, SPI_CS_PIN);
  #else
    Adafruit_CH1116 display(SCREEN_WIDTH, SCREEN_HEIGHT, &Wire, -1, DISPLAY_I2C_CLOCK);
  #endif
  #define DISPLAY_WHITE SH110X_WHITE
  #define DISPLAY_BLACK SH110X_BLACK
#elif DISPLAY_TYPE == 1
  // SH1106 display
  #if DISPLAY_INTERFACE == 1
    Adafruit_SH1106G display(SCREEN_WIDTH, SCREEN_HEIGHT, &SPI, SPI_DC_PIN, SPI_RST_PIN, SPI_CS_PIN);
  #else
    Adafruit_SH1106G display(SCREEN_WIDTH, SCREEN_HEIGHT, &Wire, -1, DISPLAY_I2C_CLOCK);
  #endif
  #define DISPLAY_WHITE SH110X_WHITE
  #define DISPLAY_BLACK SH110X_BLACK
#else
  // SSD1306 display (also drives 2.42" SSD1309 panels via the same driver)
  #if DISPLAY_INTERFACE == 1
    Adafruit_SSD1306 display(SCREEN_WIDTH, SCREEN_HEIGHT, &SPI, SPI_DC_PIN, SPI_RST_PIN, SPI_CS_PIN);
  #else
    Adafruit_SSD1306 display(SCREEN_WIDTH, SCREEN_HEIGHT, &Wire, -1, DISPLAY_I2C_CLOCK);
  #endif
  #define DISPLAY_WHITE SSD1306_WHITE
  #define DISPLAY_BLACK SSD1306_BLACK
#endif

// ========== Global State ==========
Settings settings;
MetricData metricData;
bool displayAvailable = false;
bool ntpSynced = false;
unsigned long lastNtpSyncTime = 0;
unsigned long lastReceived = 0;
unsigned long wifiDisconnectTime = 0;
unsigned long nextDisplayUpdate = 0;
bool wifiConnected = false;  // WiFi connection status for icon display
bool httpForceClock = false;  // HTTP override to force clock mode (via /api/mode/clock)
bool httpForceViz = false;    // HTTP override to force the audio visualizer (via /api/mode/viz)
#if VIZ_DEBUG_FB
float measuredFps = 0.0f;     // Frames/s actually pushed to the panel (debug builds only)
#endif

#if TOUCH_BUTTON_ENABLED
bool manualClockMode = false;  // Manual override to force clock mode when PC is online
#endif

// ========== Forward Declarations ==========
// Redundant forward declarations removed (covered by headers)
void displayStats();
void displayStatsCompactGrid();
void displayMetricCompact(Metric *m);
void drawProgressBar(int x, int y, int width, Metric *m);
int getOptimalRefreshRate();
// ========== Module Includes ==========
#include "display/display.h"
#include "clocks/clocks.h"
#include "clocks/clock_globals.h"
#include "metrics/metrics.h"
#include "network/network.h"
#include "web/web.h"


// ========== Helper Functions ==========

const char* getResetReasonName() {
  switch (esp_reset_reason()) {
    case ESP_RST_POWERON:  return "POWERON";
    case ESP_RST_EXT:      return "EXT";
    case ESP_RST_SW:       return "SW";
    case ESP_RST_PANIC:    return "PANIC";
    case ESP_RST_INT_WDT:  return "INT_WDT";
    case ESP_RST_TASK_WDT: return "TASK_WDT";
    case ESP_RST_WDT:      return "WDT";
    case ESP_RST_DEEPSLEEP:return "DEEPSLEEP";
    case ESP_RST_BROWNOUT: return "BROWNOUT";
    case ESP_RST_SDIO:     return "SDIO";
    default:               return "UNKNOWN";
  }
}

// One non-blocking read of the system clock. getLocalTime(info, 0) cannot be
// used for this: it stamps millis(), then loops while elapsed <= budget, so a
// millisecond tick landing in between skips every attempt and reports failure.
// In a render loop that shows up as content vanishing for single frames.
bool peekLocalTime(struct tm *info) {
  time_t now;
  time(&now);
  localtime_r(&now, info);
  return info->tm_year > 120;
}

// Helper function to get time with short timeout
bool getTimeWithTimeout(struct tm *timeinfo, unsigned long timeout_ms) {
  if (!ntpSynced) {
    if (getLocalTime(timeinfo, timeout_ms)) {
      // Verify time is reasonable (year > 2020) before accepting
      if (timeinfo->tm_year > 120) { // tm_year is years since 1900
        ntpSynced = true;
        lastNtpSyncTime = millis();
        Serial.println("NTP successfully synchronized");
        return true;
      }
    }
    return false;
  }
  return getLocalTime(timeinfo, timeout_ms);
}

// Selectable clock styles, in the order the touch button walks them. Ids match
// AnimatedPixelClock so a style ported later keeps the same number on both
// devices; 4 is a legacy alias for 3 and 12-15 are that project's styles we
// have not ported, so neither appears here.
const uint8_t CLOCK_STYLES[] = {0, 1, 2, 3, 5, 6, 7, 8, 9, 10, 11, 16};
const uint8_t CLOCK_STYLE_COUNT = sizeof(CLOCK_STYLES) / sizeof(CLOCK_STYLES[0]);

bool isValidClockStyle(uint8_t id) {
  if (id == 4) return true;  // legacy alias for Space Invaders
  for (uint8_t i = 0; i < CLOCK_STYLE_COUNT; i++) if (CLOCK_STYLES[i] == id) return true;
  return false;
}

uint8_t nextClockStyle(uint8_t current) {
  for (uint8_t i = 0; i < CLOCK_STYLE_COUNT; i++)
    if (CLOCK_STYLES[i] == current) return CLOCK_STYLES[(i + 1) % CLOCK_STYLE_COUNT];
  return CLOCK_STYLES[0];
}

#if TOUCH_BUTTON_ENABLED
// A style picked with the touch button is a real choice, so persist it the way
// the web form does - it used to live in RAM only and was lost on the next
// reboot. Preferences skips writing a value that has not changed, so this costs
// one key per tap.
void advanceClockStyleFromTouch() {
  settings.clockStyle = nextClockStyle(settings.clockStyle);
  resetClockAnimationState();
  saveSettings();
  Serial.print("Touch button: Clock style -> ");
  Serial.println(settings.clockStyle);
}
#endif

// Single source of truth for mode precedence. The visualizer outranks both
// stats and clock: it is only ever on because something explicitly asked for
// it, and it stops asking on its own once the stream dies.
DisplayMode currentDisplayMode() {
  if (httpForceViz && vizShouldDisplay()) return MODE_VIZ;
#if TOUCH_BUTTON_ENABLED
  if (metricData.online && !manualClockMode && !httpForceClock) return MODE_METRICS;
#else
  if (metricData.online && !httpForceClock) return MODE_METRICS;
#endif
  return MODE_CLOCK;
}

// Returns optimal refresh rate in Hz based on current display mode
int getOptimalRefreshRate() {
  // Checked before the manual-rate override: the visualizer is a transient,
  // explicitly requested mode, and a manual 2 Hz parked for burn-in reasons
  // should not freeze the bars. Capped rather than free-running - these
  // controllers have no double buffering, so pushing frames faster than the
  // panel scans them out shows up as tearing.
  if (currentDisplayMode() == MODE_VIZ) {
    return settings.vizRefreshHz;
  }

  if (settings.refreshRateMode == 1) {
    // Manual mode - use user-specified rate
    return settings.refreshRateHz;
  }

  // Auto mode - adaptive based on content
#if TOUCH_BUTTON_ENABLED
  if (!metricData.online || manualClockMode) {
#else
  if (!metricData.online) {
#endif
    // Clock mode (offline OR manual clock mode)

#if TOUCH_BUTTON_ENABLED
    // Immediately boost to 40 Hz when in manual clock mode for animated clocks
    if (manualClockMode && settings.boostAnimationRefresh &&
        (settings.clockStyle == 0 || settings.clockStyle == 3 ||
         settings.clockStyle == 4 || settings.clockStyle == 5 ||
         settings.clockStyle == 6 || settings.clockStyle == 7 ||
         settings.clockStyle == 8 || settings.clockStyle == 9 ||
         settings.clockStyle == 10 || settings.clockStyle == 11 ||
         settings.clockStyle == 16)) {
      return 60; // Instant boost for smooth manual clock mode
    }
#endif

    // Check for animation boost (smooth animations during active motion)
    if (settings.boostAnimationRefresh && isAnimationActive()) {
      // Animation is happening - boost to 40 Hz for silky smooth motion!
      return 60;
    }

    if (settings.clockStyle == 0 || settings.clockStyle == 3 ||
        settings.clockStyle == 4 || settings.clockStyle == 5 ||
        settings.clockStyle == 6 || settings.clockStyle == 7 ||
        settings.clockStyle == 8 || settings.clockStyle == 9 ||
        settings.clockStyle == 10 || settings.clockStyle == 11 ||
        settings.clockStyle == 16) {
      // Animated clocks (Mario, Space Invaders, Space Ship, Pong, Pac-Man, Snake, Tetris, Cycle, Asteroids, Dino)
      return 20; // 20 Hz keeps character movement smooth
    } else {
      // Static clocks (Standard, Large)
      return 2; // 2 Hz is plenty for clock that updates once/second
    }
  } else {
    // Metrics mode (online)
    return 10; // 10 Hz for PC stats (updates every 500ms from Python)
  }
}

// --- Clock screen rotation ---
// The rotation is a list of style:seconds pairs the user orders in the web UI,
// so durations are elapsed time rather than wall-clock 5-minute blocks.
#include "clocks/cycle_config.h"

// Animated clocks fire their minute-change animation at :56 and it runs on into
// the next minute, so switching the instant a duration expires clipped the
// animation. Hold the switch back while one is in flight, with a cap so a stuck
// animation can never wedge the rotation.
const uint32_t CYCLE_ANIM_GRACE_MS = 6000;

void cycleClockScreens() {
    static char previous[sizeof(settings.cycleConfig)] = "";
    static CycleEntry entries[CYCLE_COUNT];
    static unsigned index = 0;
    static uint32_t started = 0, lastRendered = 0;
    static int lastStyle = -1;

    uint32_t now = millis();

    // Reparse when the config changes, and when the rotation was not the active
    // renderer for a while - leaving and re-entering style 9 restarts it.
    if (strcmp(previous, settings.cycleConfig) || now - lastRendered > 2000) {
        if (!parseCycleConfig(settings.cycleConfig, entries))
            parseCycleConfig(CYCLE_DEFAULT, entries);
        strcpy(previous, settings.cycleConfig);
        index = 0;
        started = now;
    }
    lastRendered = now;

    uint32_t elapsed = now - started;
    if (entries[index].seconds && elapsed >= entries[index].seconds * 1000UL &&
        (!time_overridden || elapsed >= entries[index].seconds * 1000UL + CYCLE_ANIM_GRACE_MS)) {
        index = (index + 1) % CYCLE_COUNT;
        started = now;
    }

    // Skip disabled entries. parseCycleConfig guarantees at least one is left.
    for (unsigned n = 0; n < CYCLE_COUNT && !entries[index].seconds; ++n) {
        index = (index + 1) % CYCLE_COUNT;
        started = now;
    }

    if (lastStyle != entries[index].style) {
        resetClockAnimationState();
        lastStyle = entries[index].style;
    }

    // Each draw function handles the no-time case with its own message.
    switch (entries[index].style) {
        case 0: displayClockWithMario(); break;
        case 1: displayStandardClock(); break;
        case 2: displayLargeClock(); break;
        case 3: displayClockWithSpaceInvader(); break;
        case 5: displayClockWithPong(); break;
        case 6: displayClockWithPacman(); break;
        case 7: displayClockWithSnake(); break;
        case 8: displayClockWithTetris(); break;
        case 10: displayClockWithAsteroids(); break;
        case 11: displayClockWithDino(); break;
        case 16: displayClockWithTron(); break;
    }
}

// ========== setup() ==========
void setup() {
  Serial.begin(115200);
  delay(1000);

  Serial.printf("Boot reason: %s\n", getResetReasonName());

  // Load settings from flash
  loadSettings();

  // Initialize display
  displayAvailable = initDisplay();

  // Apply saved brightness setting
  if (displayAvailable) {
    applyDisplayBrightness();
  }

#if LED_PWM_ENABLED
  // Initialize LED PWM night light
  initLEDPWM();
  setLEDBrightness(settings.ledBrightness);
#endif

  if (!displayAvailable) {
    Serial.println("WARNING: Display not available, continuing without display");
  } else {
    display.clearDisplay();
    display.setTextColor(DISPLAY_WHITE);
    display.setTextSize(1);
    display.setCursor(10, 20);
    display.println("PC Monitor");
    display.setCursor(10, 35);
    display.println("Starting...");
    display.display();
  }

  // Check if hardcoded WiFi credentials are provided
  bool useManualWiFi = (strlen(HARDCODED_WIFI_SSID) > 0);

  if (useManualWiFi) {
    Serial.println("\n*** USING HARDCODED WIFI CREDENTIALS ***");
    if (!connectManualWiFi(HARDCODED_WIFI_SSID, HARDCODED_WIFI_PASSWORD)) {
      Serial.println("Manual WiFi connection failed!");
      Serial.println("Falling back to WiFiManager portal...");
      useManualWiFi = false;
    }
  }

#if BLE_SETUP_ENABLED
  // BLE provisioning path: fast-connect with saved creds, or BLE, or AP mode fallback
  bool bleHandled = false;
  if (!useManualWiFi) {
    if (tryConnectSavedWiFi()) {
      // Saved credentials worked — set up UDP + mDNS directly (skip WiFiManager)
      WiFi.setTxPower(WIFI_STA_TX_POWER);
      beginStatsUdp();
      initMDNS();
      bleHandled = true;
    } else if (runBleProvisioning()) {
      // BLE provisioning succeeded — WiFi already connected inside runBleProvisioning()
      WiFi.setTxPower(WIFI_STA_TX_POWER);
      beginStatsUdp();
      initMDNS();
      bleHandled = true;
    }
    // If neither worked: bleHandled = false → initNetwork() below (AP mode fallback)
  }
  if (!bleHandled && !useManualWiFi) {
    initNetwork();
  }
#else
  if (!useManualWiFi) {
    initNetwork();
  }
#endif

  // Keep the radio awake: WiFi modem sleep delays inbound ACKs to the beacon
  // interval, which stalls large web-page transfers for seconds. Power draw
  // is irrelevant next to the LED matrix.
  WiFi.setSleep(false);

  // Initialize NTP
  initNTP();

  // Apply the dimming schedule as soon as there is a clock to evaluate it
  // against. Boot brightness above is applied before WiFi/NTP, so without this
  // a restart inside a scheduled-off window lit the panel until the first
  // periodic check a minute later.
  refreshDisplayBrightnessNow();

  // Initialize WiFi connection status flag
  wifiConnected = (WiFi.status() == WL_CONNECTED);

  // Configure hardware watchdog timer
  esp_task_wdt_init(15, true);
  esp_task_wdt_add(NULL);

  // Initialize metricData
  metricData.count = 0;
  metricData.online = false;
  metricData.status = 0;  // No status received yet
  Serial.println("Waiting for PC stats data...");

  // Setup web server
  setupWebServer();

#if TOUCH_BUTTON_ENABLED
  // Initialize touch button
  initTouchButton();
#endif

  // Show IP address for 5 seconds (configurable via web interface). Skipped
  // when the schedule wants the panel dark, so a restart at night does not
  // light the room for five seconds.
  if (displayAvailable && settings.showIPAtBoot && !scheduledDisplayIsOff()) {
    displayConnected();
    delay(5000);
  }
}

// ========== loop() ==========
void loop() {
  // Feed watchdog
  esp_task_wdt_reset();

#if TOUCH_BUTTON_ENABLED
  updateTemporaryDisplayWake();
#endif

  // Check and apply scheduled brightness (time-based dimming)
  checkScheduledBrightness();

  // Handle web server requests
  server.handleClient();

  // Handle UDP packets - always process to track PC online status accurately
  handleUDP();

#if TOUCH_BUTTON_ENABLED
  // Handle touch button gestures
#if LED_PWM_ENABLED
  handleTouchLED(); // Hold > 1s: ramp LED brightness up/down
#endif
  // Regular short press (mode toggle / clock style cycle)
  if (checkTouchButtonPressed()) {
    if (!handleTemporaryDisplayWake()) {
      // Stops are metrics -> clock -> visualizer -> metrics, skipping the
      // ones that have nothing to show. The visualizer only joins while sound
      // is actually playing: packets keep arriving through silence, so
      // offering it then would hand the user a flat line and, before this,
      // swallowed the clock stop entirely. With clock the only stop left, a
      // tap cycles clock styles as it always did.
      bool vizStop = vizHasSignal(3000);
      bool metricsStop = metricData.online;
      if (httpForceViz) {
        httpForceViz = false;
        manualClockMode = !metricsStop;
        Serial.println("Touch button: Leaving visualizer");
      } else if (manualClockMode) {
        if (vizStop) {
          manualClockMode = false;
          httpForceViz = true;
          vizNoteForced();
          Serial.println("Touch button: Clock -> visualizer");
        } else if (metricsStop) {
          manualClockMode = false;
          Serial.println("Touch button: Clock -> metrics");
        } else {
          advanceClockStyleFromTouch();
        }
      } else if (metricsStop) {
        manualClockMode = true;
        Serial.println("Touch button: Metrics -> clock");
      } else if (vizStop) {
        httpForceViz = true;
        vizNoteForced();
        Serial.println("Touch button: Clock -> visualizer");
      } else {
        advanceClockStyleFromTouch();
      }
    }
  }
#endif

  // Check timeout
  if (millis() - lastReceived > TIMEOUT && metricData.online) {
    metricData.online = false;
#if TOUCH_BUTTON_ENABLED
    // Reset manual clock mode so PC metrics auto-show when PC comes back online
    manualClockMode = false;
#endif
    Serial.println("PC stats timeout - switching to clock mode");
  }

  // Retry NTP sync periodically if not synced
  if (!ntpSynced && millis() - lastNtpSyncTime > 30000) {
    struct tm timeinfo;
    if (getLocalTime(&timeinfo, 100)) {
      if (timeinfo.tm_year > 120) {
        ntpSynced = true;
        lastNtpSyncTime = millis();
        Serial.println("NTP sync successful (retry)");
      }
    } else {
      applyTimezone();  // SNTP client might be dead - restart it
      Serial.println("NTP retry: restarted SNTP client");
    }
    lastNtpSyncTime = millis();
  }

  // Periodic NTP re-sync even when already synced (safety net). SNTP keeps the
  // system clock valid between refreshes, so refresh the timezone/SNTP client
  // without clearing ntpSynced - dropping it would needlessly re-anchor the
  // clocks (below) every hour and could flash "Syncing time..." for a frame.
  if (ntpSynced && millis() - lastNtpSyncTime > NTP_RESYNC_INTERVAL) {
    applyTimezone();
    lastNtpSyncTime = millis();
    Serial.println("Periodic NTP re-sync triggered");
  }

  // Re-anchor the animated clocks when NTP first becomes valid (or after a
  // reconnect resync). At boot the clocks seed displayed_hour/min with a 00:00
  // fallback; if the first sync lands inside a clock's minute-change window the
  // animation advances from 00:00 instead of jumping to the real time, leaving
  // the clock stuck near 00:00 until a reboot or clock-cycle. Resetting the
  // animation state clears the stale time override, and syncDisplayedTime()
  // forces displayed_hour/min to match reality.
  static bool prevNtpSynced = false;
  if (ntpSynced && !prevNtpSynced) {
    resetClockAnimationState();
    struct tm now_tm;
    if (getLocalTime(&now_tm, 10)) {
      syncDisplayedTime(&now_tm);
    }
    // Time just became usable - settle the dimming schedule now rather than
    // waiting for the next periodic check.
    refreshDisplayBrightnessNow();
  }
  prevNtpSynced = ntpSynced;

  // Display update with adaptive refresh rate
  int targetHz = getOptimalRefreshRate();
  unsigned long frameInterval = 1000 / targetHz;

  if (millis() >= nextDisplayUpdate && displayAvailable && !isDisplayForcedOff()) {
    nextDisplayUpdate = millis() + frameInterval;

    display.clearDisplay();

    DisplayMode mode = currentDisplayMode();
    bool showStats = mode == MODE_METRICS;

    // Show error status if PC is connected but LHM has issues
    if (mode == MODE_VIZ) {
      displayVisualizer();
    } else if (showStats && metricData.status != STATUS_OK && metricData.status != 0) {
      displayErrorStatus(metricData.status);
    } else if (showStats) {
      displayStats();
    } else {
      switch (settings.clockStyle) {
      case 0:
        displayClockWithMario();
        break;
      case 1:
        displayStandardClock();
        break;
      case 2:
        displayLargeClock();
        break;
      case 3:
      case 4:
        displayClockWithSpaceInvader();
        break;
      case 5:
        displayClockWithPong();
        break;
      case 6:
        displayClockWithPacman();
        break;
      case 7:
        displayClockWithSnake();
        break;
      case 8:
        displayClockWithTetris();
        break;
      case 9:
        cycleClockScreens();
        break;
      case 10:
        displayClockWithAsteroids();
        break;
      case 11:
        displayClockWithDino();
        break;
      case 16:
        displayClockWithTron();
        break;
      default:
        displayStandardClock();
        break;
      }
    }

    display.display();
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

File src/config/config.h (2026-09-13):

/*
 * SmallOLED-PCMonitor - Global Configuration
 *
 * All structs, constants, enums, and extern global declarations.
 * Include this file in any module that needs access to shared types/globals.
 */

#ifndef CONFIG_H
#define CONFIG_H

#include <Arduino.h>
#include "user_config.h"

// ========== Version ==========
#define FIRMWARE_VERSION "1.7.0"

// ========== Constants ==========
#define MAX_METRICS 20
#define METRIC_NAME_LEN 11
#define METRIC_UNIT_LEN 8
#define TIMEOUT STATS_TIMEOUT

// ========== Metric Structures ==========
struct Metric {
  uint8_t id;
  char name[METRIC_NAME_LEN];
  char label[METRIC_NAME_LEN];  // Custom label (may differ from name)
  char unit[METRIC_UNIT_LEN];
  int value;
  uint8_t displayOrder;
  uint8_t companionId;  // ID of companion metric (0 = none)
  uint8_t position;     // Display position (0-11 for positions, 255 = hidden)
  uint8_t barPosition;  // Progress bar position (255 = no bar)
  int barMin;           // Progress bar minimum value
  int barMax;           // Progress bar maximum value
  int barWidth;         // Progress bar width in pixels
  int barOffsetX;       // Progress bar X offset
};

// Status codes for PC monitor connection
#define STATUS_OK 1
#define STATUS_API_ERROR 2
#define STATUS_LHM_NOT_RUNNING 3
#define STATUS_LHM_STARTING 4
#define STATUS_UNKNOWN_ERROR 5

struct MetricData {
  Metric metrics[MAX_METRICS];
  uint8_t count;
  char timestamp[6];  // "HH:MM\0"
  bool online;
  uint8_t status;     // Connection status code (see STATUS_* defines)
};

// ========== Settings Structure ========== 
struct Settings {
  // Clock settings
  uint8_t clockStyle;       // 0=Mario, 1=Standard, 2=Large, 3=Space Invader, 4=Space Ship, 5=Pong, 6=Pac-Man, 7=Snake, 8=Tetris, 9=Custom rotation, 10=Asteroids, 11=Dino Runner, 16=TRON
  char cycleConfig[128];    // Ordered style:seconds pairs used by style 9; 0 seconds disables
  int16_t gmtOffset;        // GMT offset in minutes (deprecated, kept for migration)
  bool daylightSaving;      // DST enabled (deprecated, kept for migration)
  char timezoneString[64];  // POSIX TZ string (e.g., "CET-1CEST,M3.5.0/02:00,M10.5.0/03:00")
  uint8_t timezoneIndex;    // Index into timezone database (for UI display)
  bool use24Hour;           // 24-hour format
  uint8_t dateFormat;       // 0=DD/MM/YYYY, 1=MM/DD/YYYY, 2=YYYY-MM-DD, 3=DD.MM.YYYY
  uint8_t clockPosition;    // 0=Center, 1=Left, 2=Right
  int8_t clockOffset;       // Fine-tune clock position (-10 to +10)
  bool showClock;           // Show clock in metrics mode

  // Display settings
  uint8_t displayType;      // 0=SSD1306, 1=SH1106
  uint8_t displayRowMode;   // 0=5 rows, 1=6 rows, 2=Large 2-row, 3=Large 3-row
  uint8_t colonBlinkMode;   // 0=Always On, 1=Blink, 2=Always Off
  uint8_t colonBlinkRate;   // Tenths of Hz (10 = 1.0 Hz)
  uint8_t refreshRateMode;  // 0=Auto, 1=Manual
  uint8_t refreshRateHz;    // Manual refresh rate (1-60 Hz)
  bool boostAnimationRefresh;  // Enable 40 Hz boost during animations
  uint8_t displayBrightness;   // Display brightness 0-255 (default: 255)

  // Scheduled dimming (night mode)
  bool enableScheduledDimming;  // Enable time-based automatic dimming
  uint8_t dimStartHour;         // Hour to start dimming (0-23)
  uint8_t dimEndHour;           // Hour to end dimming (0-23)
  uint8_t dimBrightness;        // Brightness level during dim period (0-255)

  // LED Night Light settings
#if LED_PWM_ENABLED
  bool ledEnabled;              // LED night light on/off (default: false)
  uint8_t ledBrightness;        // LED brightness 0-255 (default: 128 = 50%)
#endif

  // Touch button
#if TOUCH_BUTTON_ENABLED
  uint8_t touchButtonPin;       // GPIO carrying the TTP223 signal (default: TOUCH_BUTTON_PIN)
#endif

  // Format options
  bool useRpmKFormat;       // Show RPM as K (e.g., 1.2K instead of 1200)
  bool useNetworkMBFormat;  // Show network as MB/s instead of KB/s

  // Network settings
  char deviceName[32];          // Device name for mDNS and app (default: "smalloled")
  bool showIPAtBoot;          // Show IP address on OLED at startup (default: true)
  bool useStaticIP;
  char staticIP[16];
  char gateway[16];
  char subnet[16];
  char dns1[16];
  char dns2[16];
  uint16_t udpPort;             // Stats listener port (default: UDP_PORT, 4210)
  char ntpServer1[64];          // Primary NTP server (default: pool.ntp.org)
  char ntpServer2[64];          // Secondary NTP server (default: time.nist.gov, may be empty)

  // Mario clock settings
  uint8_t marioBounceHeight;  // Tenths (40 = 4.0)
  uint8_t marioBounceSpeed;   // Tenths (6 = 0.6)
  bool marioSmoothAnimation;  // Enable 4-frame walk cycle (default: false = 2-frame)
  uint8_t marioWalkSpeed;     // Tenths (20 = 2.0, 25 = 2.5 old/fast)
  bool marioIdleEncounters;   // Enable idle enemy encounters (default: false)
  uint8_t marioEncounterFreq; // 0=Rare(25-35s), 1=Normal(15-25s), 2=Frequent(8-15s)
  uint8_t marioEncounterSpeed; // 0=Slow, 1=Normal, 2=Fast (default: 1)
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

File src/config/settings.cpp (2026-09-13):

/*
 * SmallOLED-PCMonitor - Settings Module
 *
 * Load and save settings to ESP32 Preferences (flash storage).
 */

#include "settings.h"
#include "../config/config.h"
#include "../timezones.h"
#include "../utils/utils.h"
#include "../clocks/cycle_config.h"
#include <Preferences.h>


Preferences preferences;

uint8_t sanitizeBrightnessValue(uint8_t value) {
#if TOUCH_BUTTON_ENABLED
  return value;
#else
  return value == 0 ? 1 : value;
#endif
}

bool isZeroBrightnessAllowed() {
#if TOUCH_BUTTON_ENABLED
  return true;
#else
  return false;
#endif
}

void sanitizeBrightnessSettings() {
  settings.displayBrightness = sanitizeBrightnessValue(settings.displayBrightness);
  settings.dimBrightness = sanitizeBrightnessValue(settings.dimBrightness);
}

void loadSettings() {
  // Try to open preferences namespace (create if doesn't exist)
  if (!preferences.begin("pcmonitor",
                         false)) { // Read-write mode to create if needed
    Serial.println("WARNING: Failed to open preferences, using defaults");
    // Initialize with defaults
    settings.clockStyle = 0;
    strcpy(settings.cycleConfig, CYCLE_DEFAULT);
    settings.gmtOffset = 60;  // GMT+1 (Central European)
    settings.daylightSaving = true;
    strcpy(settings.timezoneString, "CET-1CEST,M3.5.0/02:00,M10.5.0/03:00"); // Default: Central European
    settings.use24Hour = true;
    settings.dateFormat = 0;
    settings.clockPosition = 0; // Center by default
    settings.clockOffset = 0;   // No offset by default
    settings.showClock = true;
    settings.displayRowMode = 0;         // Default: 5 rows with more spacing
    settings.useRpmKFormat = false;      // Default: Full RPM format (1800RPM)
    settings.useNetworkMBFormat = false; // Default: Full KB/s format
    strcpy(settings.deviceName, "smalloled");
    settings.colonBlinkMode = 1;         // Default: Blink
    settings.colonBlinkRate = 10; // Default: 1.0 Hz (10 = 1.0Hz in tenths)
    settings.refreshRateMode = 0; // Default: Auto
    settings.refreshRateHz = 10;  // Default manual rate: 10 Hz
    settings.boostAnimationRefresh =
        true;                        // Default: Enable smooth animation boost
    settings.displayBrightness = sanitizeBrightnessValue(255);
#if TOUCH_BUTTON_ENABLED
    settings.touchButtonPin = TOUCH_BUTTON_PIN;
#endif
    settings.enableScheduledDimming = false;
    settings.dimStartHour = 22;
    settings.dimEndHour = 7;
    settings.dimBrightness = sanitizeBrightnessValue(50);
    settings.marioBounceHeight = 35; // Default: 3.5 (35 = 3.5 in tenths)
    settings.marioBounceSpeed = 6;   // Default: 0.6 (6 = 0.6 in tenths)
    settings.marioSmoothAnimation = false; // Default: 2-frame animation
    settings.marioWalkSpeed = 20;    // Default: 2.0 (20 = 2.0 in tenths)
    settings.pongBallSpeed = 18;     // Default: 18 (1.125 px/frame)
    settings.pongBounceStrength = 3; // Default: 0.3 (3 = 0.3 in tenths)
    settings.pongBounceDamping = 85; // Default: 0.85 (85 = 0.85 in hundredths)
    settings.pongPaddleWidth = 20;   // Default: 20 pixels
    settings.pongHorizontalBounce = true; // Default: enabled
    settings.spaceCharacterType = 1; // Default: Ship (1 = Ship, 0 = Invader)
    settings.spacePatrolSpeed = 5;   // Default: 0.5 (5 = 0.5 in tenths)
    settings.spaceAttackSpeed = 25;  // Default: 2.5 (25 = 2.5 in tenths)
    settings.spaceLaserSpeed = 40;   // Default: 4.0 (40 = 4.0 in tenths)
    settings.spaceExplosionGravity = 5; // Default: 0.5 (5 = 0.5 in tenths)
    // Initialize all metrics with defaults
    for (int i = 0; i < MAX_METRICS; i++) {
      settings.metricLabels[i][0] = '\0'; // Empty = use Python name
      settings.metricNames[i][0] = '\0';  // Empty = no stored name
      settings.metricOrder[i] = i;        // Default order
      settings.metricCompanions[i] = 0;   // No companion by default
      settings.metricPositions[i] =
          255; // Default: None/Hidden (user must assign position)
      settings.metricBarPositions[i] = 255; // Default: No progress bar
      settings.metricBarMin[i] = 0;
      settings.metricBarMax[i] = 100;
      settings.metricBarWidths[i] =
          60; // Default width (60px for left, 64px for right)
      settings.metricBarOffsets[i] = 0; // Default: no offset
    }
    Serial.println("Settings initialized with defaults");
    return;
  }
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

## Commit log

2026-09-13 feat: configurable touch pin and LED HTTP control
    Two things the carrier PCB needed.
    The TTP223 signal pin is a board decision, not a firmware one: the
    reference wiring uses GPIO 7 while the carrier routes it elsewhere. The
    pin moves into settings with a validator that rejects the flash bus, the
    display bus, USB and the LED output, and rebinds the input immediately
    so no restart is needed. A stale NVS value or a config imported from a
    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
2026-09-13 feat(clock): custom rotation with per-clock durations
    Style 9 was a fixed tour of every clock, five minutes each, driven by
    wall-clock minute blocks. It is now a rotation the user builds: which
    clocks take part, in what order, and how long each one holds (5-3600s).
    Ported from AnimatedPixelClock, which has carried this for a while.
    The config is a "style:seconds" list in NVS; zero seconds disables an
    entry, and the parser rejects a list that leaves nothing enabled, so the
    rotation can never end up with no screen to draw. A list written by a
    firmware with fewer styles is still read, keeping its order and
    durations, with the newer styles appended disabled. The stock value is
    the old behaviour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
    [config.h, main.cpp, settings.cpp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]
2026-09-14 docs(readme): add rendered OLED screen gallery
    Fifteen 128x64 mono GIFs rendered straight from the firmware renderers on a
    PC, so the README shows what each screen actually does instead of describing
    it. No device, no camera, no reflections off the panel.
    Clock styles are captured at the 09:59 -> 10:00 rollover, the busiest case,
    since all four digits change at once. Each clip ends once that style has
    settled, so the lengths differ: Mario 8s through to Tetris 24s.
    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
2026-09-16 fix(touch): tap no longer also toggles the LED
    checkTouchButtonPressed() and handleTouchLED() both act on a single press
    but run in different loop iterations, and each measured the press duration
    itself. The short-press branch kicks off advanceClockStyleFromTouch() ->
    saveSettings(), which is ~245 ms of NVS on the device, so by the time
    handleTouchLED() saw the release its own millis() - buttonPressStartTime
    had grown past the 500 ms medium-press threshold. A ~300 ms tap therefore
    cycled the clock style and then toggled the night light, even though the
    two gestures are meant to be mutually exclusive.
    Sample the duration once, at the moment the release is detected, and have
    both consumers cl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
    [utils.cpp]
2026-09-19 docs(readme): point web flasher links at smalloled.stolaris.dev
    The flasher has its own domain via docs/CNAME, and the assembly video shows
    that address on screen. The two README links still sent people to the
    github.io URL.
2026-09-19 docs: add carrier PCB page with PCBWay credit, photos and case files
    PCBWay sponsored the project and manufactured the carrier boards, SMT assembly
    included, so the credit they were promised now sits in the README and on a
    dedicated page.
    CARRIER-PCB.md carries the board spec, build photos from a 1.3" unit, the
    assembly video and the shared project link. The two enclosures only fit this
    board, so they ship here as 3MF rather than on MakerWorld. The 1.3" case needs a
    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
    [SmallOLED-Case-0.96-PCB.3mf, SmallOLED-Case-1.3-Retro-PCB.3mf]
